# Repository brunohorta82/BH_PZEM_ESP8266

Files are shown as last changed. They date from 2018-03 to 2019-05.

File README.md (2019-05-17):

# BH PZEM

**Conteúdo **   
1. [Intro](#id1)
2. [Hardware](#id2)
3. [Firmware](https://github.com/brunohorta82/BH-Easy-Iot)
4. [Hack de sentido da corrente](#id4)
5. [Exemplos](#id5)
   - [BH PZEM-004 Wi-Fi](#id6)
5. [Donativos](#id7)

## Intro 

**BH Pzem** é um dispositivo baseado em ESP8266 e PZEM-004 que mede energia e / ou temperatura e enviaos dados a um broker MQTT e / ou Emoncms. O BH Pzem é modular, o que significa que podemos começar com um simples módulo de energia até um sistema de monitorização de produção energética, juntamente com detecção de temperatura (até 10 sensores de temperatura digital). Podemos ainda adicionar um diplay Oled e relés.
Os dados são enviados via Wi-Fi

**Painel de Controlo:**
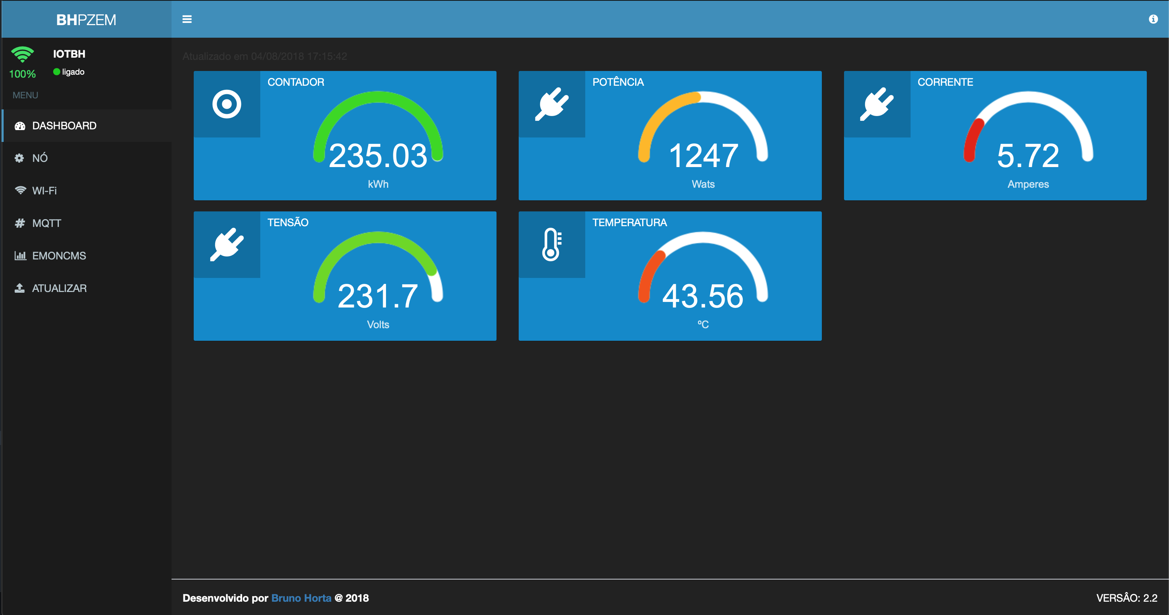
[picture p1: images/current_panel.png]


**Medição de Energia:**
  - Baseado no PZEM-004
  - Leituras muito rigorosas 
  - Possibilidade de detecão de sentido de energia 
  - Voltagem, Amperagem, Potência, Energia

**Medição de Temperatura:**
  - Baseado no sendor 1-wire DS18B20
  - Permite adicionar até 10 sensores digitais DS18B20
  - Endereços dos sensores geridos na interface Web

**Relé :**
  - Controlado via MQTT

**ESP8266**:
  - Facilmente configurado na Interface Web
  - Envio dos dados em JSON via MQTT
  - Envio dos dados para um servidor Emoncms local/remoto
  
## Hardware 

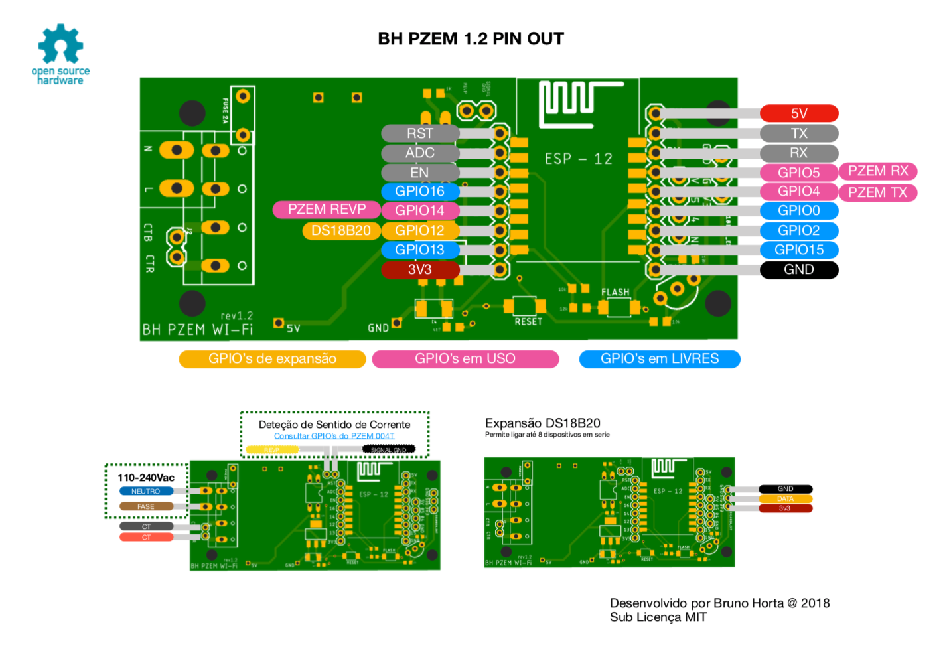
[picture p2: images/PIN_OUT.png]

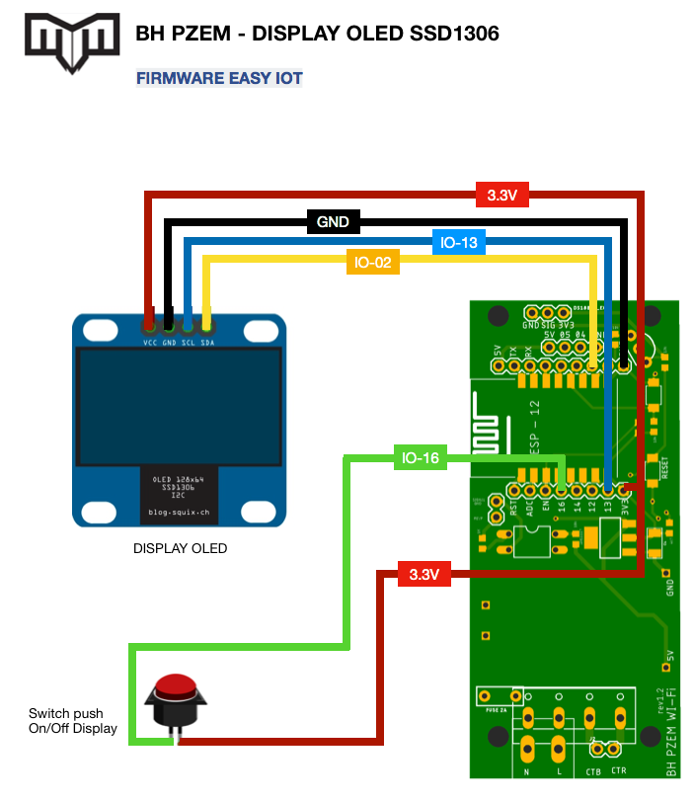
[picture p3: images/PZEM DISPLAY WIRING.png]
BHPZemOled


Qtd | Item | Imagem
:---: | :---: | ---:
1 | PZEM-004 | `...`
1 | ESP-12E | `...`
1 | PCB BH-PZEM Wi-Fi | `...`
1 | Fonte HLK-PM01 | `...`
1 | Regulador de Tensão AMS1117 3.3v | `...`
1 | Condensador Cerâmico 100nF SMD | `...`
5 | Resistência 10K 0603 | `...`
1 | Resistência 4.7K 0603 | `...`
1 | Resistência 1K 0603 | `...`
1 | Optocopolador PC | `...`
2 | Botão 3*4*2 MM SMD | `...`
1 | Fusível T2A 2A 250 | `...`
1 | Sensor temperatua DS18B20 | `...`
1 | Terminal de Parafuso 2P 5.0mm  | `...`
2 | Terminal 2P 2.54mm  | `...`
1 | Conector de 9 Pinos Fêmea 2.54mm | `...`
1 | Conector de 8 Pinos Fêmea 2.54mm | `...`
1 | Conector de 4 Pinos Macho 2.54mm | `...`
1 | Conector de 7 Pinos Macho 2.54mm | `...`

## Software 

- Arduino Ide
- Editar o ficheiro config.h com o setup inicial
- Upload do Firmware para o ESP8266
- Aceder ao AP `SSID:BH_PZEM_NODE_ID` e configurar a Rede Wi-Fi
- Navegar até  `http://<bh-pzem name>.local` ou `http://<bh-pzem IP address>`
- Verificar o sentido da corrente caso tenham feito o Hack para a deteção
- Configurar o `MQTT broker` e/ou a conta do `Emoncms` 
- E tá feito, agora é só curtir :) 

## Hack para deteção de sentido de corrente 

![](https://lh3.googleusercontent.com/7oKvPvdqY3lP6zBprZ33XxJ7tKCSPjcxN2w-OqwHl_1SzNu80wvdnXQUsuom1qUd44zljcSAKoW6R_QD6Fw6dyNdrQpZGyCAt7fK76CRAaeEPu2qT8z-xMeqMLAlgMNtwaD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)

## Exemplos de BH-PZEM 

### BH PZEM-004 Wi-Fi 
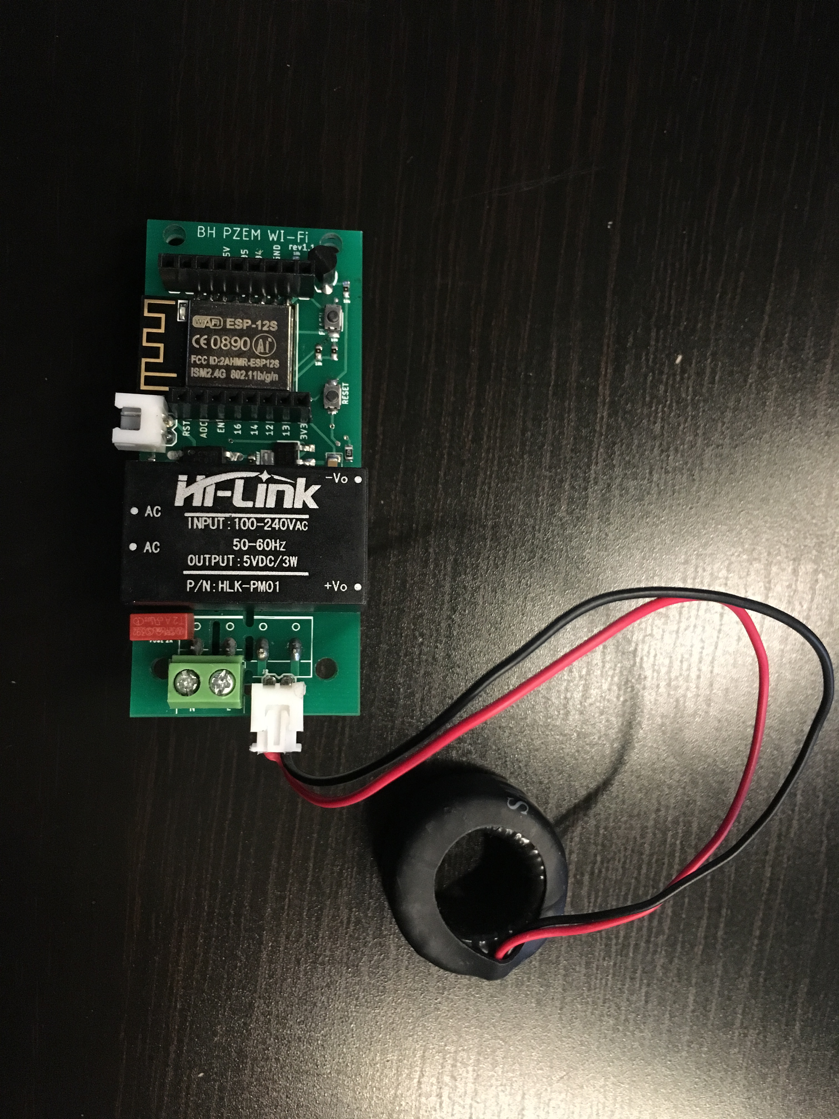
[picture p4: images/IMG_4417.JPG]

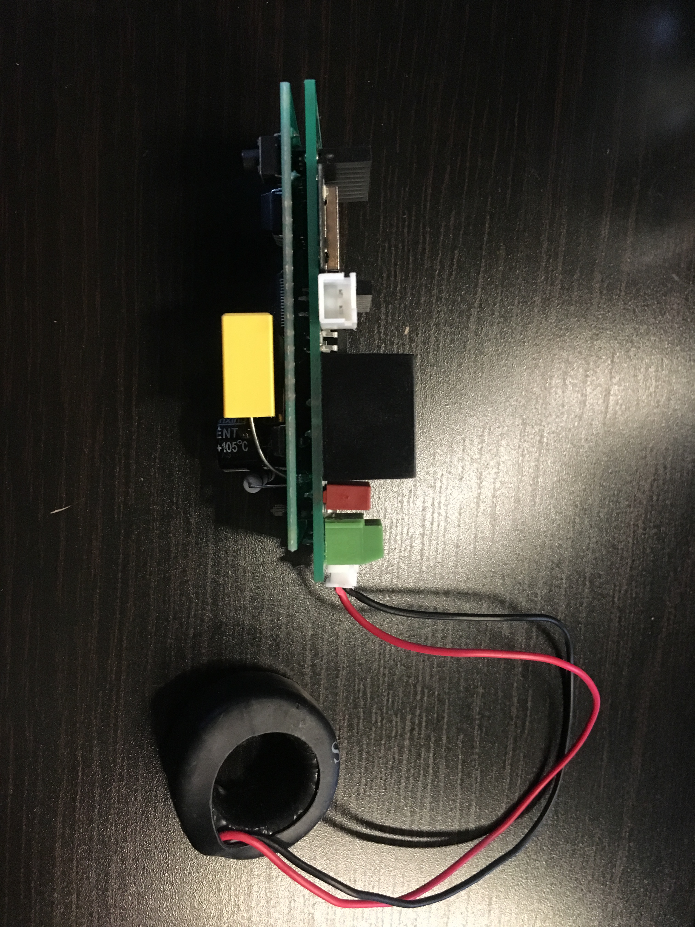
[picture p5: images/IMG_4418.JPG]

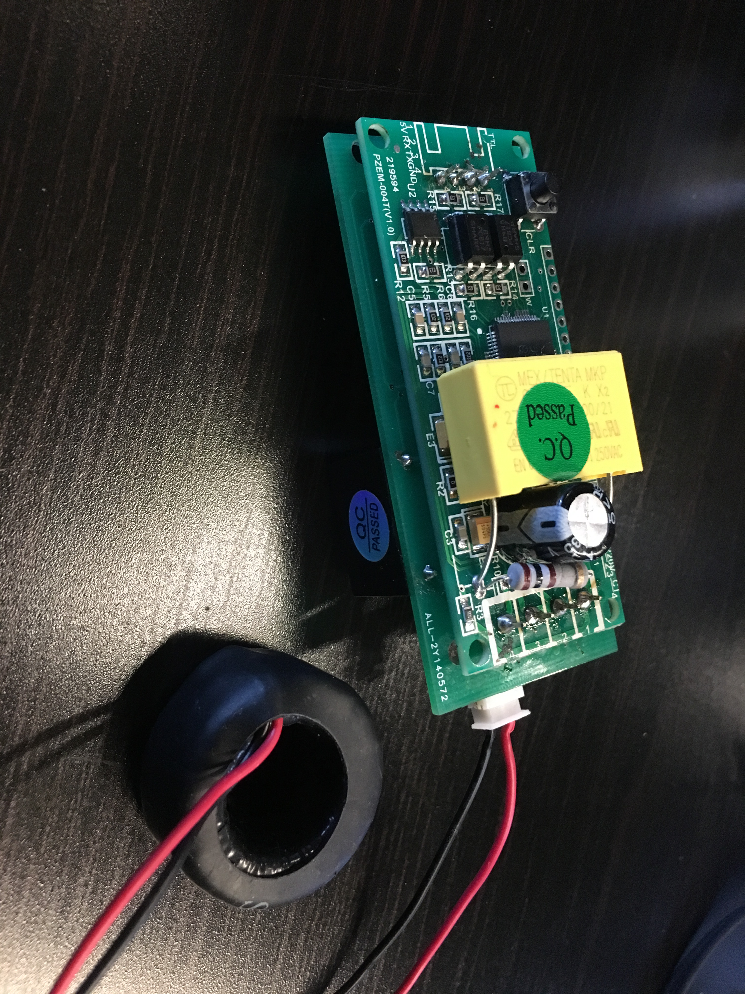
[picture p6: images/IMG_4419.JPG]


## Caixas e Adaptadores
 - [BHPZEM Suporte DIN Powered by Bruno Horta](https://cad.onshape.com/documents/db83fdb5f2287efd0e4b6ae1/w/3f678a7db5145870a715b4d4/e/e8a96d2384c3348520138283)

## Donativos

Se gostas-te do projeto podes fazer o teu donativo :).



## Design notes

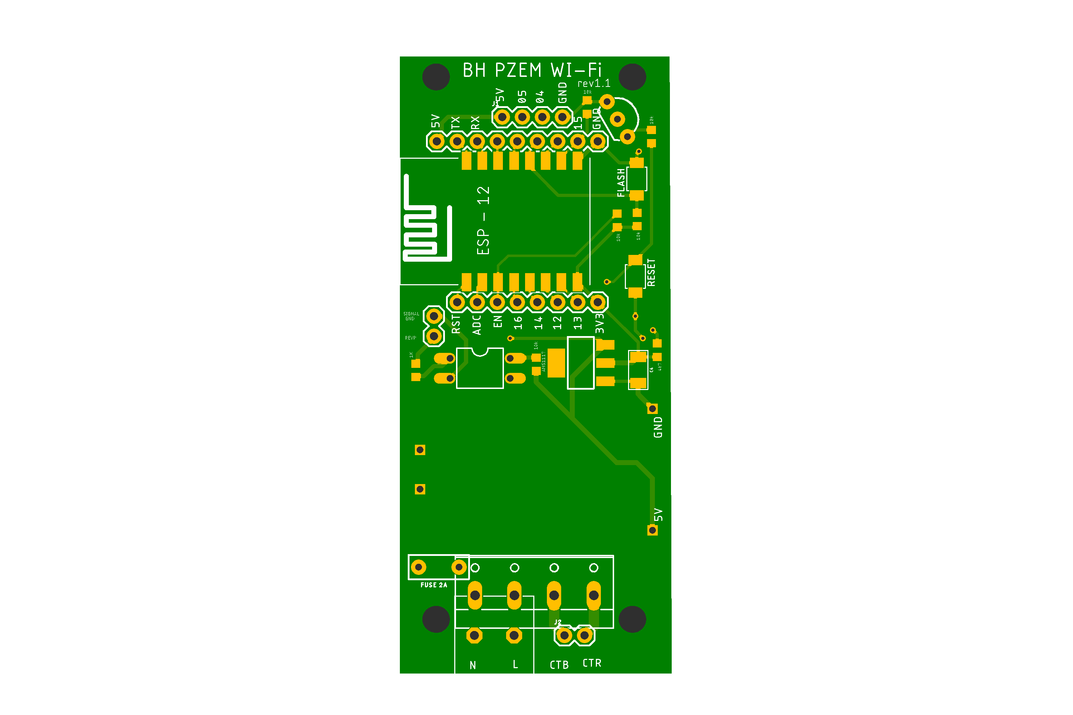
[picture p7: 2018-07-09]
Docs/BH_Pzem_WI_FI_SHIELD_R1.1.png

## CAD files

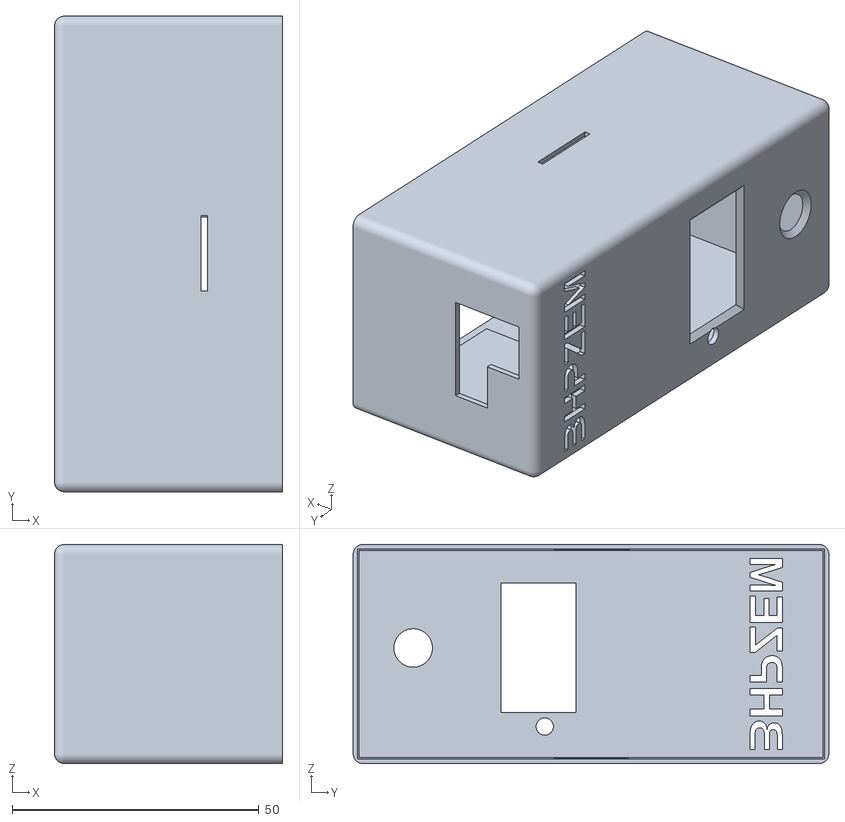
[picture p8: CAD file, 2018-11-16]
caixas/PZEM - TampaLCD.stl
46.2 x 96.4 x 44.4

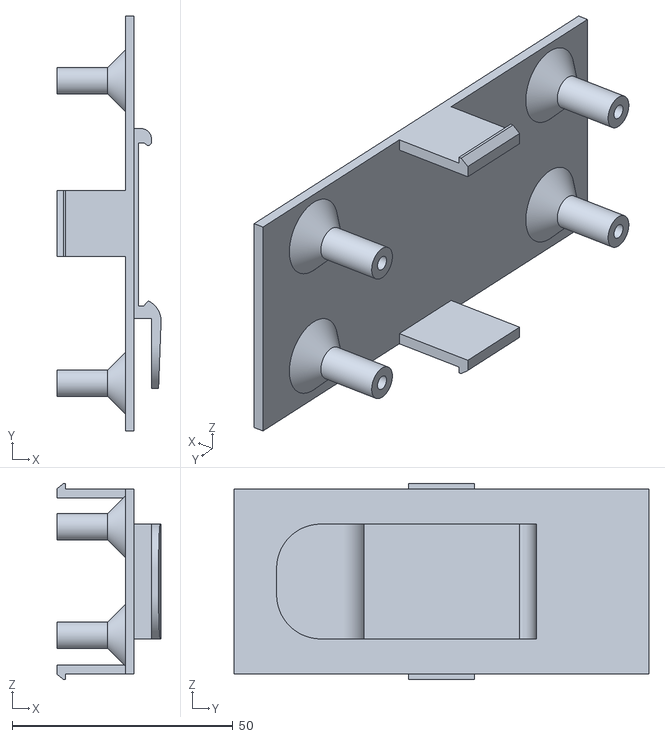
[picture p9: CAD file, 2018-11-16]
caixas/PZEM - BaseDin.stl
23.6 x 94.0 x 44.4

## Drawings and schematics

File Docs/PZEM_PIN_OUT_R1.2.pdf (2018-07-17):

### BH PZEM 1.2 PIN OUT

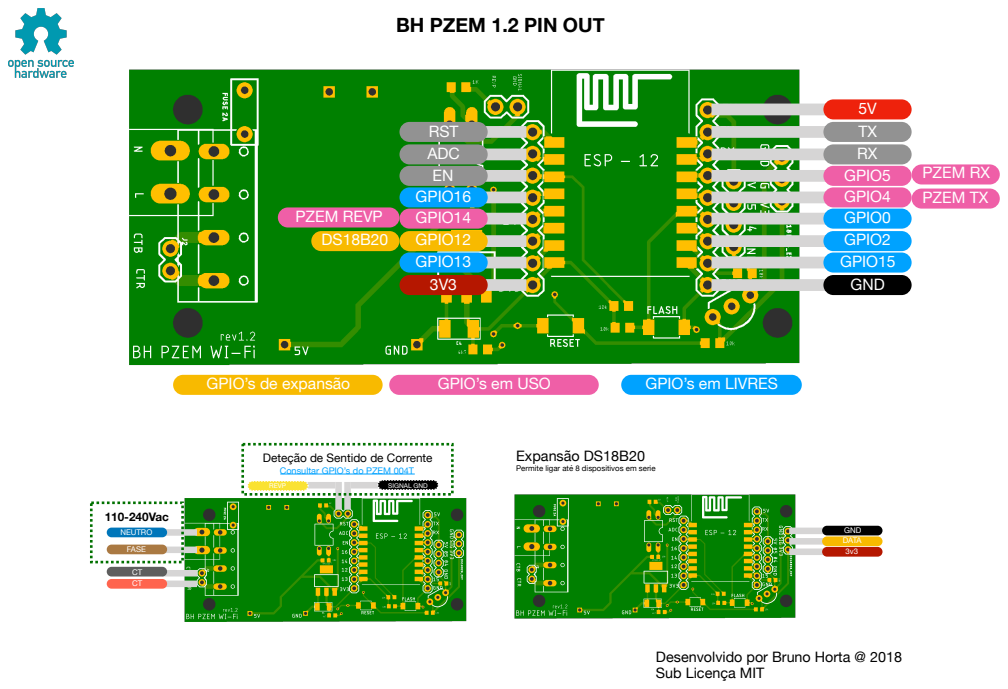
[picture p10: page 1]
5V TX RX GPIO5 GPIO4 GPIO0 GPIO2 GPIO15 GND; RST ADC EN GPIO16 GPIO14 GPIO12 GPIO13 3V3; PZEM RX PZEM TX; PZEM REVP DS18B20; GPIO’s em USO; GPIO’s em LIVRES; GND DATA 3v3; NEUTRO; FASE; 110-240Vac; REVP; SIGNAL GND

GPIO’s de expansão

Deteção de Sentido de Corrente
Consultar GPIO’s do PZEM 004T

Expansão DS18B20
Permite ligar até 8 dispositivos em serie

Desenvolvido por Bruno Horta @ 2018
Sub Licença MIT

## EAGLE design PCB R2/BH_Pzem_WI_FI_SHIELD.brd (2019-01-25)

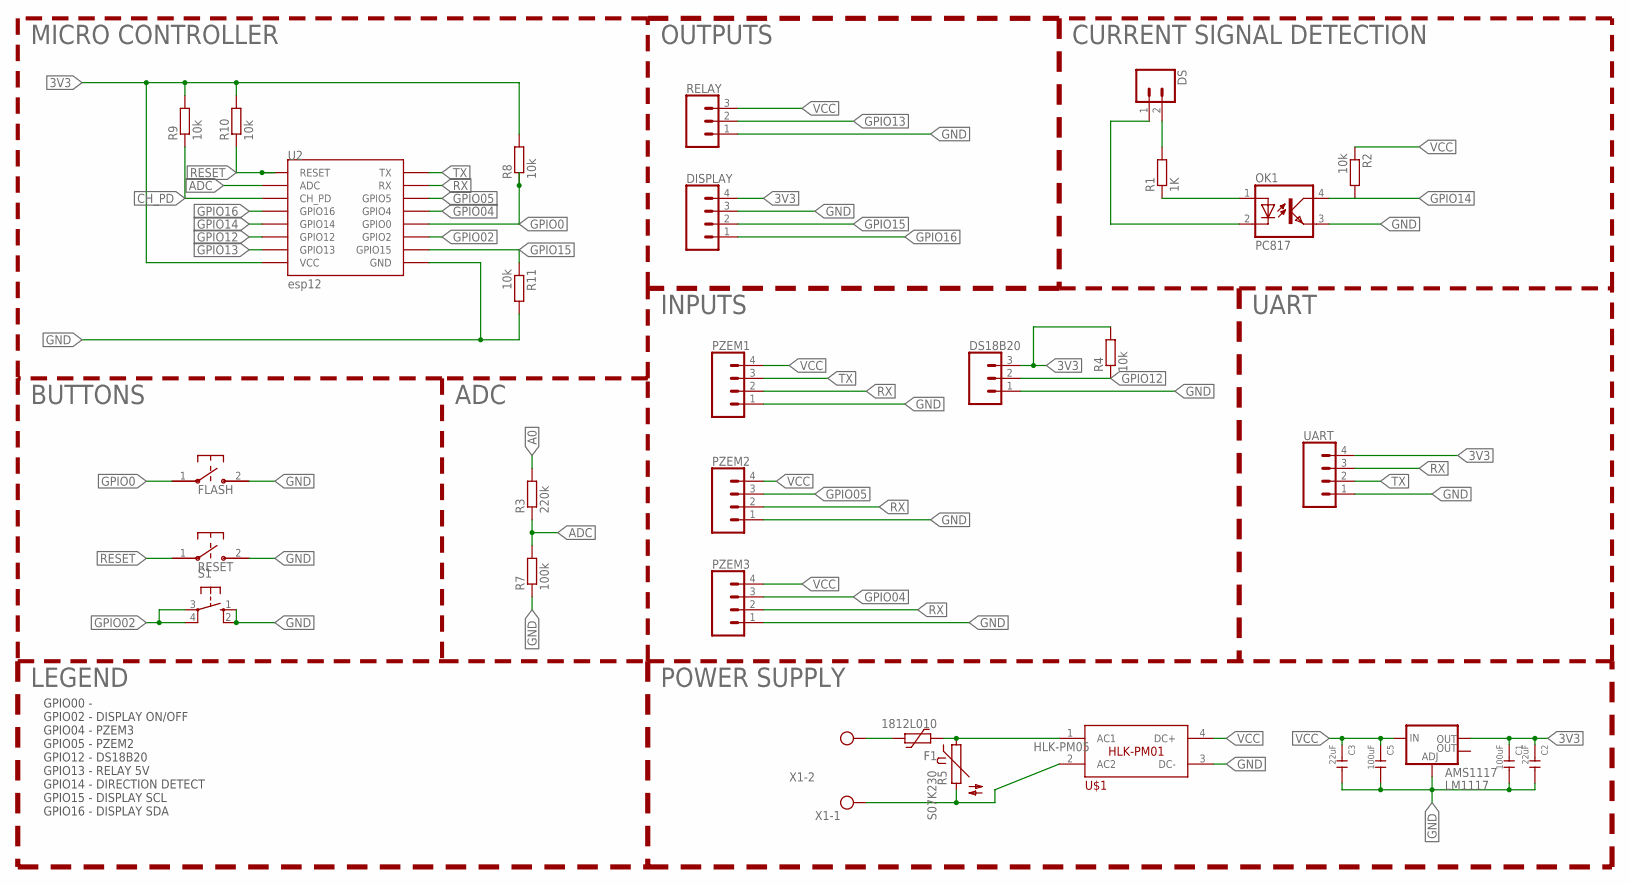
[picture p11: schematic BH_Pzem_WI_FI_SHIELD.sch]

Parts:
AMS1117: LM1117; SOT223
C1, C5: 100uF; C1206
C2, C3: 22uF; C1206
DISPLAY: CONN_04JST-PTH-VERT; JST-4-PTH-VERT
DS: CONN_02; 1X02
DS18B20: CONN_03JST-PTH-VERT; JST-3-PTH-VERT
F1: 1812L010; 1812L
FLASH: B3U-1000P-2P-SMD; B3U-1000P
OK1: PC817; DIL04
PZEM1, PZEM2, PZEM3: CONN_04JST-PTH-VERT; JST-4-PTH-VERT
R1: 1K; R0603
R2, R4, R8, R9, R10, R11: 10k; R0603
R3: 220k; R0603
R5: S07K230
R7: 100k; R0603
RELAY: CONN_03JST-PTH-VERT; JST-3-PTH-VERT
RESET: B3U-1000P-2P-SMD; B3U-1000P
S1: 10-XX; B3F-10XX
U2: esp12; ESP12-SMD
U$1: HLK-PM01
UART: CONN_04JST-PTH-VERT; JST-4-PTH-VERT
X1: W237-102

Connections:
3V3: AMS1117.2 (OUT), C1.1, C2.1, DISPLAY.4, DS18B20.3, R4.2, R8.2, R9.2, R10.2, U2.VCC, UART.4
A0: R3.2
ADC: R3.1, R7.2, U2.ADC
CH_PD: R9.1, U2.CH_PD
GND: AMS1117.1 (ADJ), C1.2, C2.2, C3.2, C5.2, DISPLAY.3, DS18B20.1, FLASH.2, OK1.3 (EMIT), PZEM1.1, PZEM2.1, PZEM3.1, R7.1, R11.2, RELAY.1, RESET.2, S1.1 (S), S1.2 (S1), U2.GND, U$1.3 (DC-), UART.1
GPIO0: FLASH.1, R8.1, U2.GPIO0
GPIO02: S1.3, S1.4 (P1), U2.GPIO2
GPIO04: PZEM3.3, U2.GPIO4
GPIO05: PZEM2.3, U2.GPIO5
GPIO12: DS18B20.2, R4.1, U2.GPIO12
GPIO13: RELAY.2, U2.GPIO13
GPIO14: OK1.4 (COL), R2.2, U2.GPIO14
GPIO15: DISPLAY.2, R11.1, U2.GPIO15
GPIO16: DISPLAY.1, U2.GPIO16
LINE_L: F1.2, R5.1, U$1.1 (AC1)
unnamed: OK1.1 (A), R1.1
unnamed: F1.1, X1.2
unnamed: DS.2, R1.2
NEUTRAL_IN: R5.2, U$1.2 (AC2), X1.1
RESET: R10.1, RESET.1, U2.RESET
RX: PZEM1.2, PZEM2.2, PZEM3.2, U2.RXD0 (RX), UART.3
SIGNAL_GND: DS.1, OK1.2 (C)
TX: PZEM1.3, U2.TXD0 (TX), UART.2
VCC: AMS1117.3 (IN), C3.1, C5.1, PZEM1.4, PZEM2.4, PZEM3.4, R2.1, RELAY.3, U$1.4 (DC+)

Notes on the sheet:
CURRENT SIGNAL DETECTION
INPUTS
BUTTONS
MICRO CONTROLLER
HLK-PM05
ADC
OUTPUTS
GPIO00 - GPIO02 - DISPLAY ON/OFF GPIO04 - PZEM3 GPIO05 - PZEM2 GPIO12 - DS18B20 GPIO13 - RELAY 5V GPIO14 - DIRECTION DETECT GPIO15 - DISPLAY SCL GPIO16 - DISPLAY SDA
POWER SUPPLY
LEGEND
UART

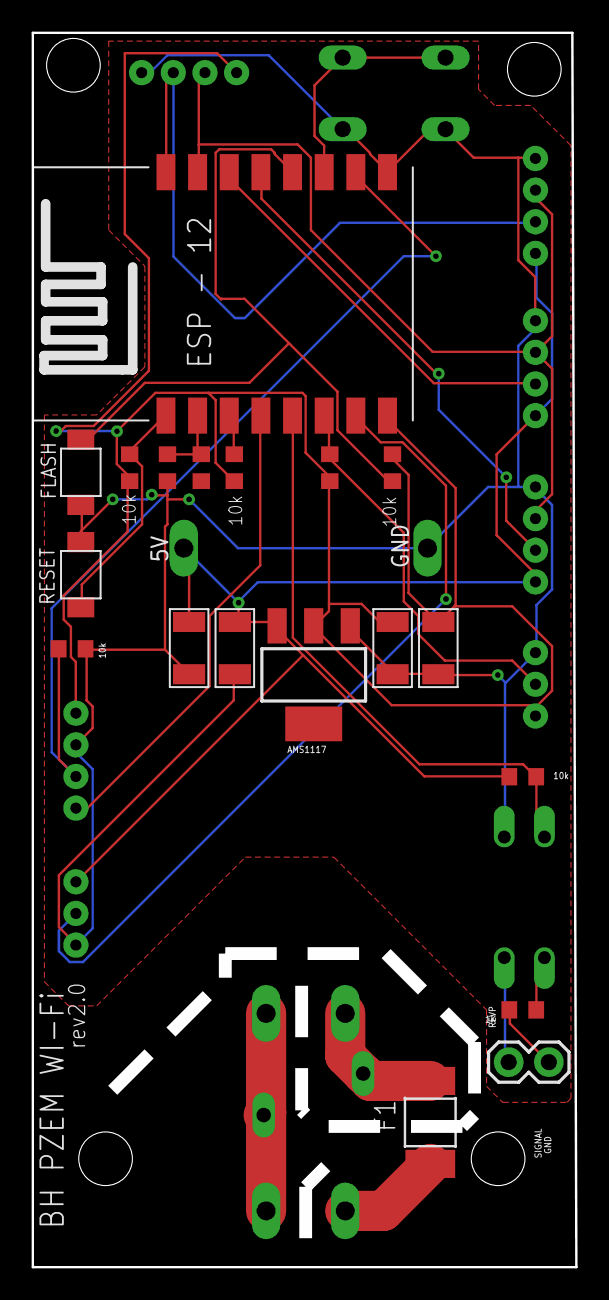
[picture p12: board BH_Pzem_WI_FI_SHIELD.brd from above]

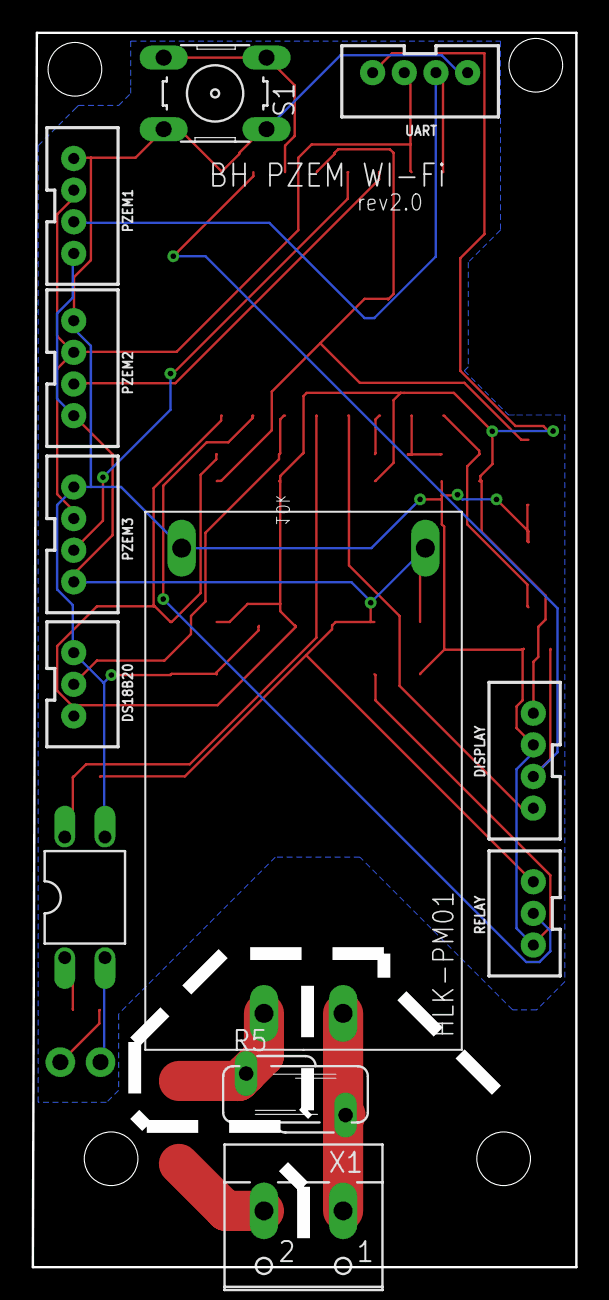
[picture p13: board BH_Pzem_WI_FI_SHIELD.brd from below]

Board: 2 copper layers, 34.3 x 78.0 mm, 31 parts (12 on the bottom side), 23 nets.

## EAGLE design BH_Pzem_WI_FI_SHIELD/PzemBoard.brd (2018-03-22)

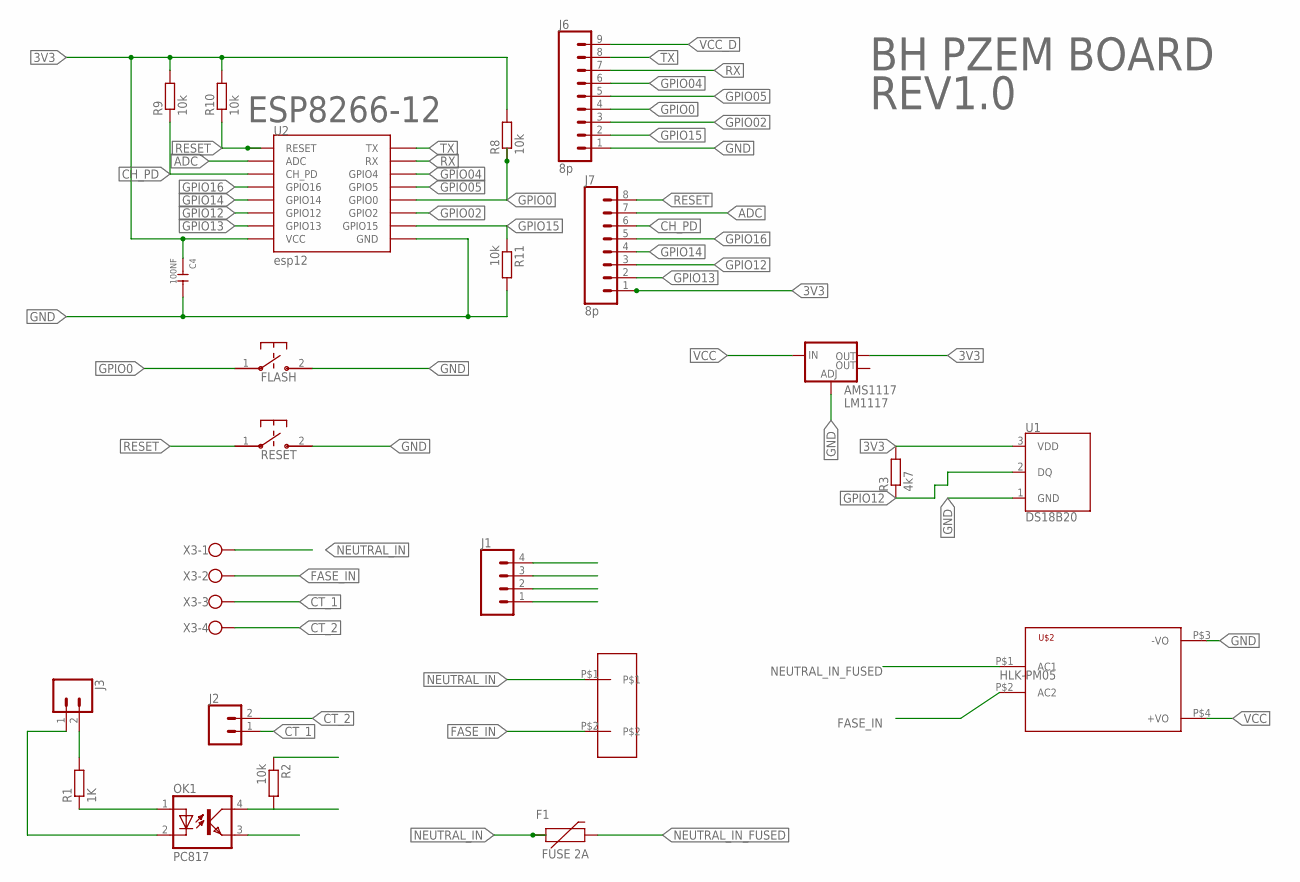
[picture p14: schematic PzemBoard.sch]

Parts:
AMS1117: LM1117; SOT223
C4: 100NF; C1206
F1: FUSE 2A; PTH
FLASH: B3U-1000P-2P-SMD; B3U-1000P
J1: CONN_04; 1X04
J2, J3: CONN_02; 1X02
J6: 8p; 1X09
J7: 8p; 1X08
OK1: PC817; DIL04
R1: 1K; R0603
R2, R8, R9, R10, R11: 10k; R0603
R3: 4k7; R0603
RESET: B3U-1000P-2P-SMD; B3U-1000P
U1: DS18B20; TO-92-AMMO
U2: esp12; ESP12-SMD
U$1: SCREWTERMINALS_5MM_2; TERMINAL_2X
U$2: HKLPM01
X3: W237-4

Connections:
3V3: AMS1117.2 (OUT), C4.1, J7.1, R3.2, R8.2, R9.2, R10.2, U1.3 (VDD), U2.VCC
ADC: J7.7, U2.ADC
CH_PD: J7.6, R9.1, U2.CH_PD
CT_1: J2.1, X3.3
CT_2: J2.2, X3.4
FASE_IN: U$1.P$2, U$2.P$2 (AC2), X3.2
GND: AMS1117.1 (ADJ), C4.2, FLASH.2, J1.4, J6.1, OK1.3 (EMIT), R11.2, RESET.2, U1.1 (GND), U2.GND, U$2.P$3 (-VO)
GPIO0: FLASH.1, J6.4, R8.1, U2.GPIO0
GPIO02: J6.3, U2.GPIO2
GPIO04: J1.2, J6.6, U2.GPIO4
GPIO05: J1.3, J6.5, U2.GPIO5
GPIO12: J7.3, R3.1, U1.2 (DQ), U2.GPIO12
GPIO13: J7.2, U2.GPIO13
GPIO14: J7.4, OK1.4 (COL), R2.2, U2.GPIO14
GPIO15: J6.2, R11.1, U2.GPIO15
GPIO16: J7.5, U2.GPIO16
unnamed: OK1.1 (A), R1.1
unnamed: J3.2, R1.2
NEUTRAL_IN: F1.P$1 (1), U$1.P$1, X3.1
NEUTRAL_IN_FUSED: F1.P$2 (2), U$2.P$1 (AC1)
RESET: J7.8, R10.1, RESET.1, U2.RESET
RX: J6.7, U2.RXD0 (RX)
SIGNAL_GND: J3.1, OK1.2 (C)
TX: J6.8, U2.TXD0 (TX)
VCC: AMS1117.3 (IN), R2.1, U$2.P$4 (+VO)
VCC_D: J1.1, J6.9

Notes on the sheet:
HLK-PM05
BH PZEM BOARD
ESP8266-12
REV1.0

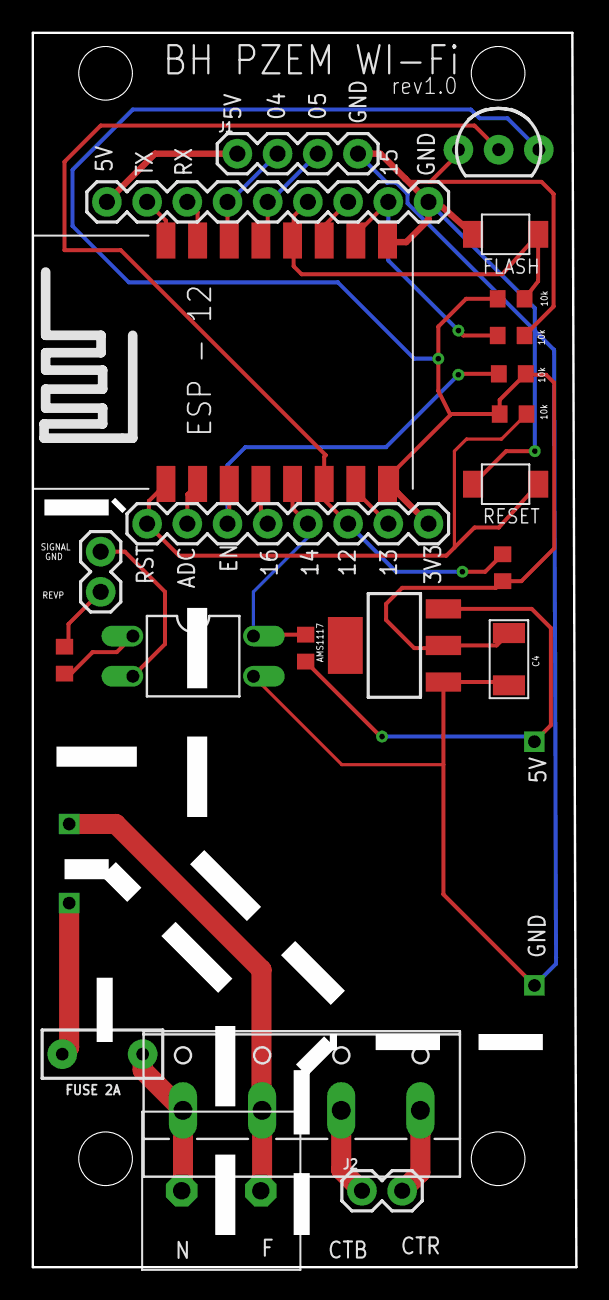
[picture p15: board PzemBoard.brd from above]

Board: 2 copper layers, 34.3 x 78.0 mm, 23 parts (1 on the bottom side), 26 nets.

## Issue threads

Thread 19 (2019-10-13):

Sentido da corrente no pzem 004 v3

ruimiguelsa, 2019-10-13:
Olá Bruno,
Comprei uns pzem 004, a versão que veio é a V3, sabes se se consegue medir o sentido da corrente como a versao inicial onde isso era possível e como falas neste teu artigo? Cumprimentos

openbr2, 2022-08-21:
gostaria de saber também

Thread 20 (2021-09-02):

PZEM v2 HA discovery no longer working

drthanwho, 2021-09-02:
Since the last  firmware for the PZEM v2 the necessary information for HA auto discovery has changed. Namely `hass` became `homeassitant`.

Any chance for an updated version so that the device is autodiscovered instead of having to manually add everything?

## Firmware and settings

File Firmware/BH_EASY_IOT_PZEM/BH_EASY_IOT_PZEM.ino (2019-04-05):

/*

BH FIRMWARE

Copyright (C) 2017-2018 by Bruno Horta <brunohorta82 at gmail dot com>

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
*/



#include "Config.h"
void checkServices(){
  if(laodDefaults){
    SPIFFS.format();
    shouldReboot = true;
  }

  if(wifiUpdated){
    saveConfig();
    reloadWiFiConfig();
    wifiUpdated = false;
    }
  if(needScan()){
      scanNewWifiNetworks();
   }
   if(reloadMqttConfiguration){
     setupMQTT();
   }
}

void setup() {
  Serial.begin(115200);
  loadStoredConfiguration();
  setupWiFi(); 
  setupWebserver(); 
  setupBHPzem();
  setupDisplay();
  
}

void loop() {
   MDNS.update();
   if(autoUpdate){
    autoUpdate = false;
    actualUpdate();
    }
  
  if(adopted){
   saveConfig();
   shouldReboot = true;
   adopted = false;
  }
   if(shouldReboot){
    logger("Rebooting...");
    shouldReboot = false;
    ESP.restart();
    return;
  }
  
    loopBHPzem();
  
  loopWiFi();
  checkServices();
  mqttMsgDigest();
  
}

void actualUpdate(){
  WiFiClient client;
     ESPhttpUpdate.update(client, getUpdateUrl());
 
}

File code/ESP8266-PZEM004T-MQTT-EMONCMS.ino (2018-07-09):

#include "config.h"
#include <Timing.h> //https://github.com/scargill/Timing
//ESP
#include <ESP8266WiFi.h>
//Wi-Fi Manger library https://www.youtube.com/watch?v=wWO9n5DnuLA
#include <DNSServer.h>
#include <ESP8266WebServer.h>
#include <WiFiManager.h>//https://github.com/tzapu/WiFiManager
#ifdef EMONCMS_HTTPS
#include <WiFiClientSecure.h>
#endif

#include <PZEM004T.h> //https://github.com/olehs/PZEM004T

//TEMPERATURA
#include <OneWire.h>
#include <DallasTemperature.h> //https://github.com/milesburton/Arduino-Temperature-Control-Library

IPAddress pzemIP(192, 168, 1, 1);
PZEM004T pzem(RX_PIN, TX_PIN);
Timing timerRead;
//DALLAS
OneWire oneWire(DS18B20_PIN);
DallasTemperature DS18B20(&oneWire);

void setup() {
  
  Serial.begin(115200);
  timerRead.begin(0);
  WiFiManager wifiManager;
  //reset saved settings
  //wifiManager.resetSettings();
  /*define o tempo limite até o portal de configuração ficar novamente inátivo,
   útil para quando alteramos a password do AP*/
  wifiManager.setTimeout(180);
  if(!wifiManager.autoConnect(HOSTNAME)) {
    Serial.println("failed to connect and hit timeout");
    delay(3000);
    ESP.restart();
    delay(5000);
  } 
  
  //PZEM SETUP
  pzem.setAddress(pzemIP);
  prepareWebserverUpdate();
  pinMode(DIRECTION_PIN,INPUT);
  #if MQTT
  Serial.println("*MQTT: ON");
  #endif
  #ifdef EMONCMS_API_KEY  and EMONCMS_HOST
  Serial.println("*EMONSCMS: ON");
  #endif
  #ifdef DEBUG
  Serial.println("*DEBUG: ON");
  #endif
  #if DETECT_DIRECTION
  Serial.println("*CURRENT DIRECTION DETECTION: ON");
  #endif
  #ifdef D_SSD1306
  setupDisplay();
  #endif
}

void loop() {
  
  
  #if MQTT
  if (checkMqttConnection()) {
    mqttLoop();
  }       
  #endif
  if (WiFi.status() == WL_CONNECTED) {
      webUpdateServerLoop() ;
      if (timerRead.onTimeout(DELAY_NOTIFICATION)){
        float v =  getVoltage();
        float i =  getCurrent();
        float p =  getPower()*directionSignal();
        float e =  getEnergy();
        float t =  requestTemperature();
      #ifdef D_SSD1306
      printOnDisplay(v,i,p);
      #endif  
      #if PRINT_TO_SERIAL_MONITOR  
        Serial.print("T; ");
        Serial.print(t); 
        Serial.print(v);  
        Serial.print("V; ");
        Serial.print(i);
        Serial.print("A; ");
        Serial.print(p);
        Serial.print("W; ");
        Serial.print(e);
        Serial.print("Wh; ");
        Serial.println();
      #endif
      String json = "{temperatura:"+String(t)+",voltagem:" + String(v) + ",amperagem:" + String(i) + ",potencia:" + String(p) + ",contador:" + String(e)+",config:" + String(CONFIG_VERSION) +"}";
      #if MQTT
        publishData(json);
       #endif
       #ifdef EMONCMS_API_KEY
          String url = String(EMONCMS_URL_PREFIX)+ "/input/post?node="+String(NODE_ID)+"&apikey="+String(EMONCMS_API_KEY)+"&json="+json;
          #if EMONCMS_PROTOCOL == 0 //HTTP
            WiFiClient clienthttp;
            if (!clienthttp.connect(EMONCMS_HOST,HTTP_PORT)) {
              Serial.println("connection failed");
              return;
            }
            clienthttp.print(String("GET ") + url + " HTTP/1.1\r\n" +
                       "Host: " + String(EMONCMS_HOST) + "\r\n" +
                       "Connection: close\r\n\r\n");
            unsigned long timeout = millis();
            while (clienthttp.available() == 0) {
              
              if (millis() - timeout > 5000) {
                Serial.println(">>> Client Timeout !");
                clienthttp.stop();
                return;
              }
            }
        #endif
        #if EMONCMS_PROTOCOL == 1 //HTTPS
           WiFiClientSecure clienthttps;
      
        if (!clienthttps.connect(EMONCMS_HOST,HTTPS_PORT)) {
          Serial.println("connection failed");
          return;
        }
      
        clienthttps.print(String("GET ") + url + " HTTP/1.1\r\n" +
                   "Host: " + String(EMONCMS_HOST) + "\r\n" +
                   "Connection: close\r\n\r\n");
        unsigned long timeout = millis();
        while (clienthttps.available() == 0) {
          if (millis() - timeout > 5000) {
            Serial.println(">>> Client Timeout !");
            clienthttps.stop();
            return;
          }
        }
    #endif
    #endif
    }
  }
}

float requestTemperature(){
  float temp = 0;
   do {
    DS18B20.requestTemperatures(); 
    temp = DS18B20.getTempCByIndex(0);
  } while (temp == 85.0 || temp == (-127.0));
  return temp;
}



int directionSignal(){
  #if DETECT_DIRECTION
    return digitalRead(DIRECTION_PIN) ? -1 : 1;
  #else
    return 1;
  #endif
}

float getVoltage() {
  int i = 0;
  float r = -1.0;
  do {
    r = pzem.voltage(pzemIP);
    i++;

  } while ( i < MAX_ATTEMPTS && r < 0.0);
  return r;
}

float getCurrent() {
  int i = 0;
  float r = -1.0;
  do {
    r = pzem.current(pzemIP);
    i++;

  } while ( i < MAX_ATTEMPTS && r < 0.0);
  return r;
}

float getPower() {
  int i = 0;
  float r = -1.0;
  do {
    r = pzem.power(pzemIP);
    i++;
  } while ( i < MAX_ATTEMPTS && r < 0.0);
  return r;
}

float getEnergy() {
  int i = 0;
  float r = -1.0;
  do {
    r = pzem.energy(pzemIP);
    i++;

  } while ( i < MAX_ATTEMPTS && r < 0.0);
  return r;
}

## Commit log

2018-03-21 WI-FI Shield
    [PzemBoard.brd, PzemBoard.sch]
2018-03-22 pista em falta para o GND
    [PzemBoard.brd, PzemBoard.sch]
2018-04-11 Código melhorado, Board rev1.1 in progress
    [BH_Pzem_WI_FI_SHIELD_rev_1.1.brd, BH_Pzem_WI_FI_SHIELD_rev_1.1.sch]
2018-04-12 rev 1.1 board
    [BH_Pzem_WI_FI_SHIELD_rev_1.1.brd, BH_Pzem_WI_FI_SHIELD_rev_1.1.sch]
2018-04-14 Código para mostrar a temperatura com o sensor dallas ligado ao pino 12
2018-04-19 melhoramento de PCB e de código
    [BH_Pzem_WI_FI_SHIELD_rev_1.1.brd]
2018-07-06 foto da pcb
    [BH_Pzem_WI_FI_SHIELD_rev_1.1.brd]
2018-07-08 Webupdate, detecção de sentido de corrente
2018-07-09 Foto atualizada da PCB, optimização de código
2018-07-09 organização de pastas
    [BH_Pzem_WI_FI_SHIELD_rev_1.1.brd, BH_Pzem_WI_FI_SHIELD_rev_1.1.csv, BH_Pzem_WI_FI_SHIELD_rev_1.1.sch]
2018-07-11 Painel de configuração
2018-07-11 Painel de configuração, detecção dinamica de sensores de temperatura
2018-07-11 suporte para relés
2018-07-11 fix bug on ArduinoJson Lib
    [WebPanel.ino]
2018-07-11 fix bug json, painel novo
    [WebPanel.ino]
2018-07-11 Correcção dos valores estáticos no painel de controlo
2018-07-12 implementação de relés controlados por mqtt
2018-07-12 Update via Painel de Controlo (WEB)
2018-07-12 Configuração dinámica de GPIOs, licença MIT
2018-07-12 manometros de medição, bloqueio de espaços no nome do node, melhoramento do painel de controlo
2018-07-12 binário para update
2018-07-12 remoção de antigo binário
2018-07-12 servidor de desenvolvimento local para bh-pzem-esp8266-ui
2018-07-12 fix bug, atualização de Leituras
2018-07-12 novo gauge de consumo total
2018-07-12 limpeza de headers repetidos
2018-07-12 relés por MQTT, auto criação de switch no homeassistant
2018-07-13 fix scroll bug when gauge update
    [WebPanel.ino]
2018-07-13 painel de configuração atualizado, mDNS a funcionar
2018-07-13 Adicionado task no gulp para criar ficheiro static_site.h automaticamente
2018-07-13 implementação de gestão de wi-fi e reboot de device
    [WebPanel.ino]
2018-07-13 optimização no codigo de condiguração
2018-07-14 PCB REV 1.2. Melhorias - Pistas de alimentação mais largas - Orifícios de header 250v mais largos - Adicionado um header para extender o numero de sensores de temperatura (DS18b28_ext)
    [BH_Pzem_WI_FI_SHIELD.brd, BH_Pzem_WI_FI_SHIELD.sch, BH_Pzem_WI_FI_SHIELD_rev_1.1.csv]
2018-07-14 atualização de foto de pcb
2018-07-14 Melhoramento das PCB Labels
    [BH_Pzem_WI_FI_SHIELD.brd]
2018-07-14 [DOCUMENTAÇÃO] - PIN OUT
    [BH_Pzem_WI_FI_SHIELD.brd]
2018-07-16 Criação de sensores automaticamente no home assistant, display
2018-07-16 Configuração de GPIOS para o Display via WEB
2018-07-16 FIX mqtt topic para o homeassistant
    [DISPLAY_1306.ino, MQTT.ino, WebPanel.ino]
2018-07-17 pinos SDA e SCL para o display configuraveis via Web Panel
2018-07-17 alteração de cores e remoção de markup
2018-07-17 remoção de fontes desnecessárias
2018-07-17 navegaçõo de menu
2018-07-17 navegação de menu
2018-07-18 implementação do markup do Andre, reorganização de ficheiros
2018-07-18 Implementação do Novo template no Ide do Arduino
2018-07-18 implementação das fonts e css no IDE do Arduino, testes no ESP8266 OK
2018-07-19 implementação de will topic no mqtt
2018-07-19 protecão de formulários
2018-07-19 Implementação de botões para reset de fábrica e reboot
    [MQTT.ino, WebPanel.ino]
2018-07-27 Pesquisa de rede wi-fi, janela de logs, estado da ligação
2018-08-04 Novo Layout, remoção do configurador de GPIO' Online (será implementado futuramente)
2018-08-09 possibilidade de configuração de porta do EMONCMS
2018-08-31 mqtt topic name fix
    [Config.ino, MQTT.ino]
2018-11-01 Actualização de MQTT
    A temperatura não consigo
    [BH_Pzem_WI_FI_SHIELD_rev_1.1.brd, BH_Pzem_WI_FI_SHIELD_rev_1.1.csv, BH_Pzem_WI_FI_SHIELD_rev_1.1.sch]
2018-11-16 passagem de firmware para Easy Iot
    passagem de firmware para Easy Iot
2018-11-16 PCB Rev.1.2
    Expanção para Sensores de temperatura Dallas OneWire
    [BH_Pzem_WI_FI_SHIELD.brd, BH_Pzem_WI_FI_SHIELD.sch, BH_Pzem_WI_FI_SHIELD_rev_1.1.csv]
2018-11-16 docs e caixas
    [PZEM - BaseDin.stl, PZEM - TampaLCD.stl]
2018-12-13 Wiring Display
    Esquema de Ligação para Display Oled
2018-12-18 rev2.0 progress
    [BH_Pzem_WI_FI_SHIELD.brd, BH_Pzem_WI_FI_SHIELD.sch]
2019-03-25 Versão 4 Firmware
    melhoramento na estabilidade
    [copper_bottom.gbr, copper_top.gbr, drills.xln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]

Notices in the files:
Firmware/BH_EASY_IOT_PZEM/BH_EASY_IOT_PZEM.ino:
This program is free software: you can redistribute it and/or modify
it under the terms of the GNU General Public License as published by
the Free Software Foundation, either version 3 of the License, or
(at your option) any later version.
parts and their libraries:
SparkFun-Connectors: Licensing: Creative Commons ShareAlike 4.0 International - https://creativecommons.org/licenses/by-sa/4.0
